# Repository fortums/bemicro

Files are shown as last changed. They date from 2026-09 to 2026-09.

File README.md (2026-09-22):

<h1>Bemicro</h1>
A macropad designed for Hackclub's Stardance.<br>
This is a half macropad half beatmania controller inspired by the <a href="https://github.com/ianklug/bemini">Bemini</a>.<br>
This was started on the 12th, and is now concluding on the 21st. not too bad for a first hardware project, if i do say so myself.<br>

AI FREE!!
<br><br>
<h2>the board itself</h2>
This was probably the most fun part. <br>
The keys (including the encoder button) are wired in a matrix with diodes. Theres 4 Neopixel LEDs in a row, A rotary encoder, and a small OLED screen.
<br> Every pin of the Xiao RP2040 is used except for the 3.3v pin, which is unneeded here.<br>

<br>
wiring it was also pretty fun, but not as much, it was a lot of doing and then redoing.<br>
i ended up with this masterfully (horribly) wired board<br>

<br>
which looks like this in the 3d view<br>

<br><br>
<h2>The case!</h2>
its really bare bones. The Xiao, leds, keyswitches, and roatary encoder all need to be left (mostly) uncovered, so theres not much to really add a top over, so theres no top. for now.(if i feel its needed once its built, i will make one.)
<br><br>
notably, the encoder knob (to mirror a beatmania controller) looks like a tunrtable... kinda. its that odd shape so that it can still be spin-able dj style, but also not cover the whole board.<br>
<br>
the board screws into the case (with the keyswitches facing "south" and the indent in the case facing "north"). the "turntable" friction fits over the D shaft of the rotary encoder.
<h2>qmk...</h2>
man qmk was a headache. it was quite the process to get rolling, mostly the guide was not at all for this usecase. but, with some perseverance and a bit of luck i figured it out.<br>
the default keybinds are as follows.<br>
  S,  D,  F,   ESC(on rotary encoder)<br>
Z,  X,  C,  V<br><br>
The rotary encoder itself types G on a counter clockwise turn and B on a clockwise turn <br>
holding the rotary encoder button also enables the led control layer, for as long as you hold it.<br>
the binds are <br>
       Hue up,    Sat up,    Val up,    ____(you should be holding this anyways)<br>
hue down,  sat down,   val down,    toggle underglow.<br>
there isnt yet a "macro"pad layer, but there will be in the future.<br><br>
<h1>bill of materials</h1>
1x Seeed Studio Xiao RP2040<br>
8x Through-hole 1N4148 diodes<br>
7x MX-style keyswitches<br>
1x EC11E rotary encoder (the kind with a switch)<br>
1x .91 inch OLED display<br>
7x MX keycaps (white in this case)<br>
2x M3x16mm screws<br>
2x M3x5x4mm heatset inserts.<br>
4x SK6812 MINI-E LEDs

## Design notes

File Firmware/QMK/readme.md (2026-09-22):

# bemicro

bemicro

*A short description of the keyboard/project*

* Keyboard Maintainer: [cnythia nosurname](https://github.com/fortums)
* Hardware Supported: *The PCBs, controllers supported*
* Hardware Availability: *Links to where you can find this hardware*

Make example for this keyboard (after setting up your build environment):

    make bemicro:default

Flashing example for this keyboard:

    make bemicro:default:flash

See the [build environment setup](https://docs.qmk.fm/#/getting_started_build_tools) and the [make instructions](https://docs.qmk.fm/#/getting_started_make_guide) for more information. Brand new to QMK? Start with our [Complete Newbs Guide](https://docs.qmk.fm/#/newbs).

## Bootloader

Enter the bootloader in 3 ways:

* **Bootmagic reset**: Hold down the key at (0,0) in the matrix (usually the top left key or Escape) and plug in the keyboard
* **Physical reset button**: Briefly press the button on the back of the PCB - some may have pads you must short instead
* **Keycode in layout**: Press the key mapped to `QK_BOOT` if it is available

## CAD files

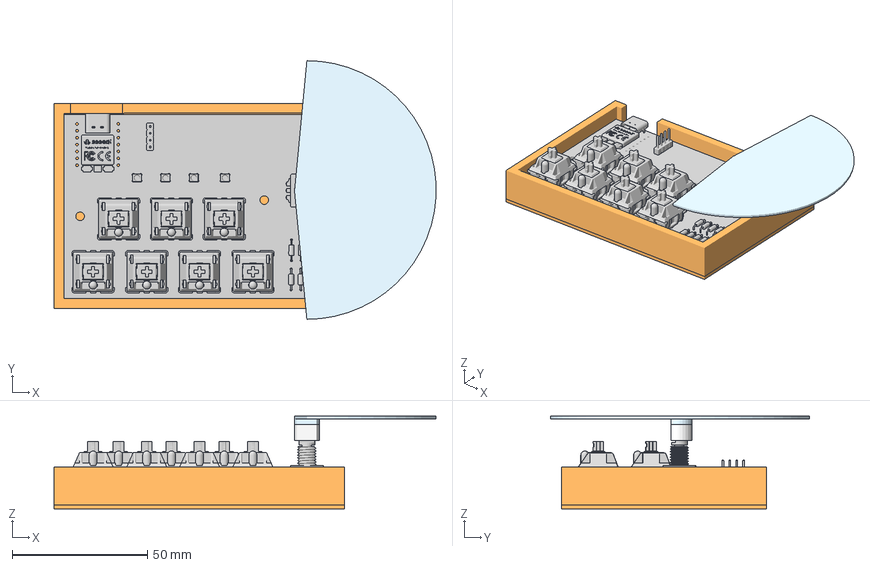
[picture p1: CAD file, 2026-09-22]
CAD/Full_Model.3mf
141.1 x 95.5 x 34.2 mm

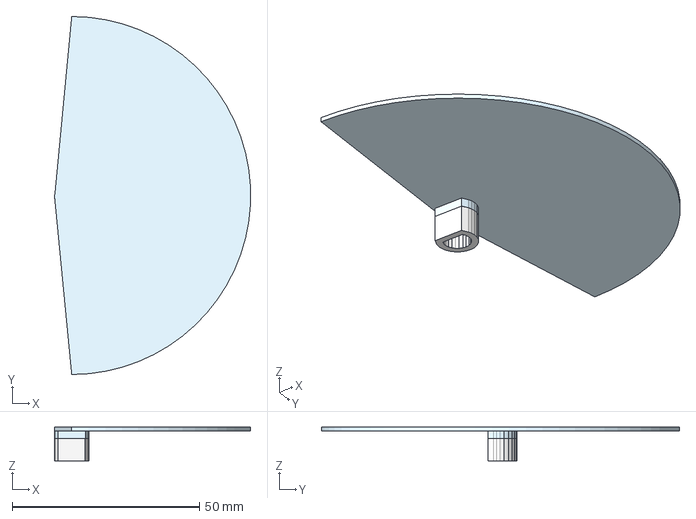
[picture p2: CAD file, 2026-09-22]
production/turntable.step
52.3 x 95.5 x 9.02 mm

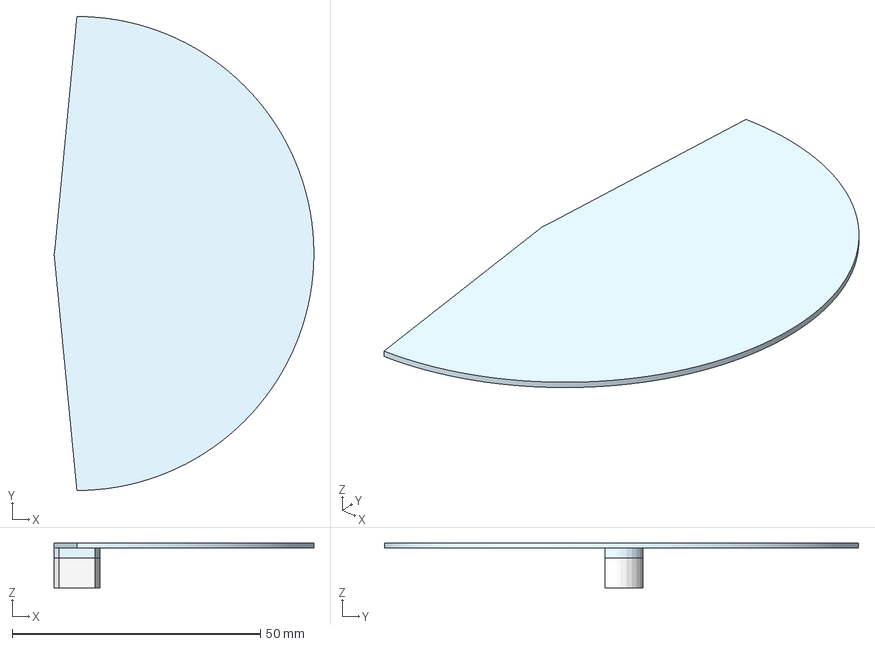
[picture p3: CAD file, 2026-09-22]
CAD/turntable.3mf
52.3 x 95.5 x 9.02 mm

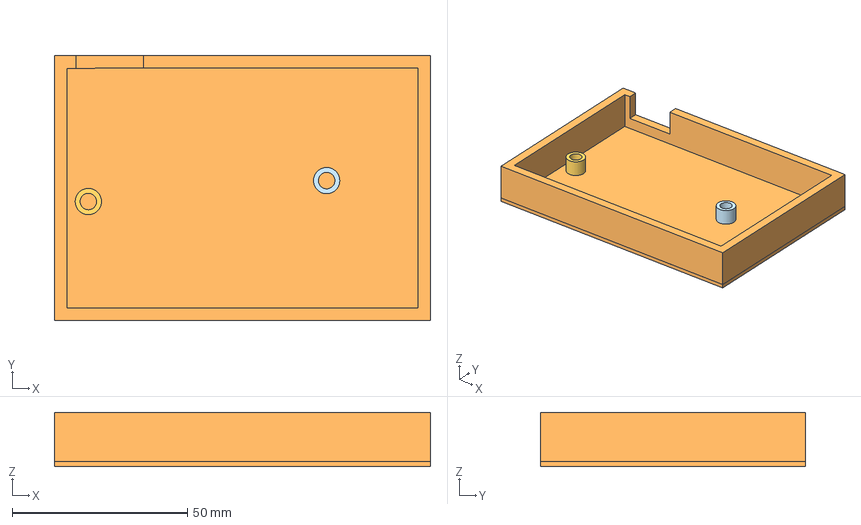
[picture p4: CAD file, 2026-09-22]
production/case_bottom.step
107.3 x 75.7 x 15.5 mm

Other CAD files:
CAD/Case_topless.3mf

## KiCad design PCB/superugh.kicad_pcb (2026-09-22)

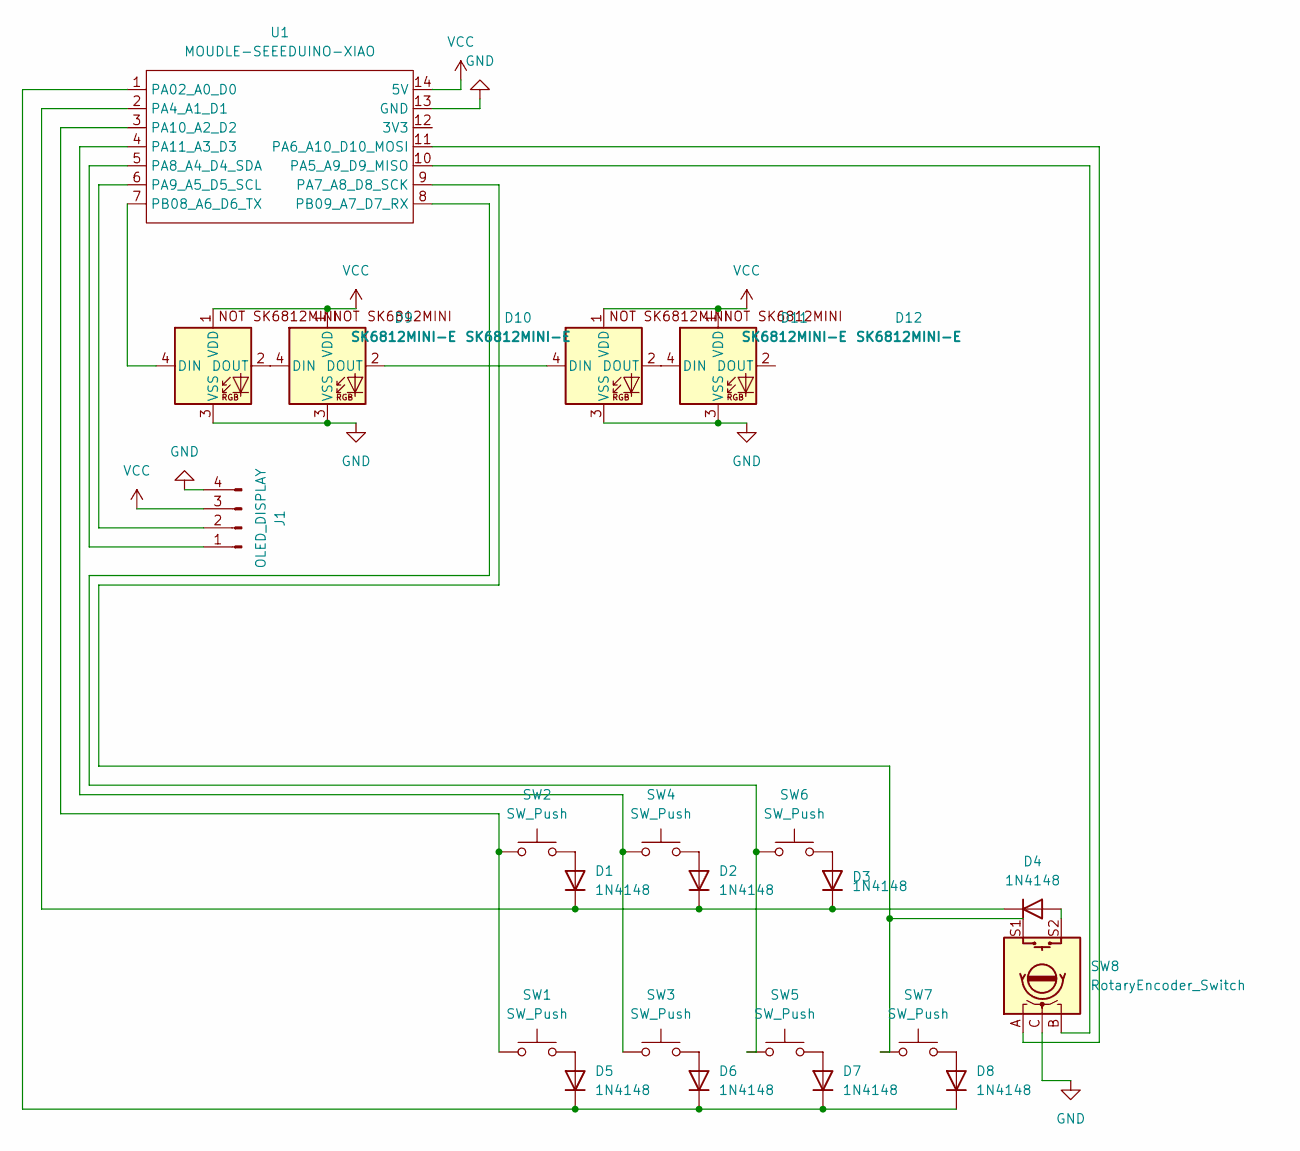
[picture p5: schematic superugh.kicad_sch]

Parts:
D1, D2, D3, D4, D5, D6, D7, D8: 1N4148; D_DO-35_SOD27_P7.62mm_Horizontal
D9, D10, D11, D12: SK6812MINI-E; LED_SK6812MINI-E_3.2x2.8mm_P1.5mm_ReverseMount
J1: OLED_DISPLAY; PinHeader_1x04_P2.54mm_Vertical
SW1, SW2, SW3, SW4, SW5, SW6, SW7: SW_Push; SW_Cherry_MX_1.00u_PCB
SW8: RotaryEncoder_Switch; RotaryEncoder_Alps_EC11E-Switch_Vertical_H20mm
U1: MOUDLE-SEEEDUINO-XIAO; XIAO-Generic-Hybrid-14P-2.54-21X17.8MM

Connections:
GND: D9.3 (VSS), D10.3 (VSS), D11.3 (VSS), D12.3 (VSS), J1.4, SW8.C, U1.13 (GND)
unnamed: D1.2 (A), SW2.2
unnamed: D1.1 (K), D2.1 (K), D3.1 (K), D4.1 (K), U1.2 (PA4_A1_D1)
unnamed: D2.2 (A), SW4.2
unnamed: D3.2 (A), SW6.2
unnamed: D4.2 (A), SW8.S2
unnamed: D5.2 (A), SW1.2
unnamed: D5.1 (K), D6.1 (K), D7.1 (K), D8.1 (K), U1.1 (PA02_A0_D0)
unnamed: D6.2 (A), SW3.2
unnamed: D7.2 (A), SW5.2
unnamed: D8.2 (A), SW7.2
unnamed: D9.4 (DIN), U1.7 (PB08_A6_D6_TX)
unnamed: D9.2 (DOUT), D10.4 (DIN)
unnamed: D10.2 (DOUT), D11.4 (DIN)
unnamed: D11.2 (DOUT), D12.4 (DIN)
unnamed: J1.1, U1.5 (PA8_A4_D4_SDA)
unnamed: J1.2, U1.6 (PA9_A5_D5_SCL)
unnamed: SW8.B, U1.10 (PA5_A9_D9_MISO)
unnamed: SW8.A, U1.11 (PA6_A10_D10_MOSI)
unnamed: SW7.1, SW8.S1, U1.9 (PA7_A8_D8_SCK)
unnamed: SW1.1, SW2.1, U1.3 (PA10_A2_D2)
unnamed: SW3.1, SW4.1, U1.4 (PA11_A3_D3)
unnamed: SW5.1, SW6.1, U1.8 (PB09_A7_D7_RX)
VCC: D9.1 (VDD), D10.1 (VDD), D11.1 (VDD), D12.1 (VDD), J1.3, U1.14 (5V)

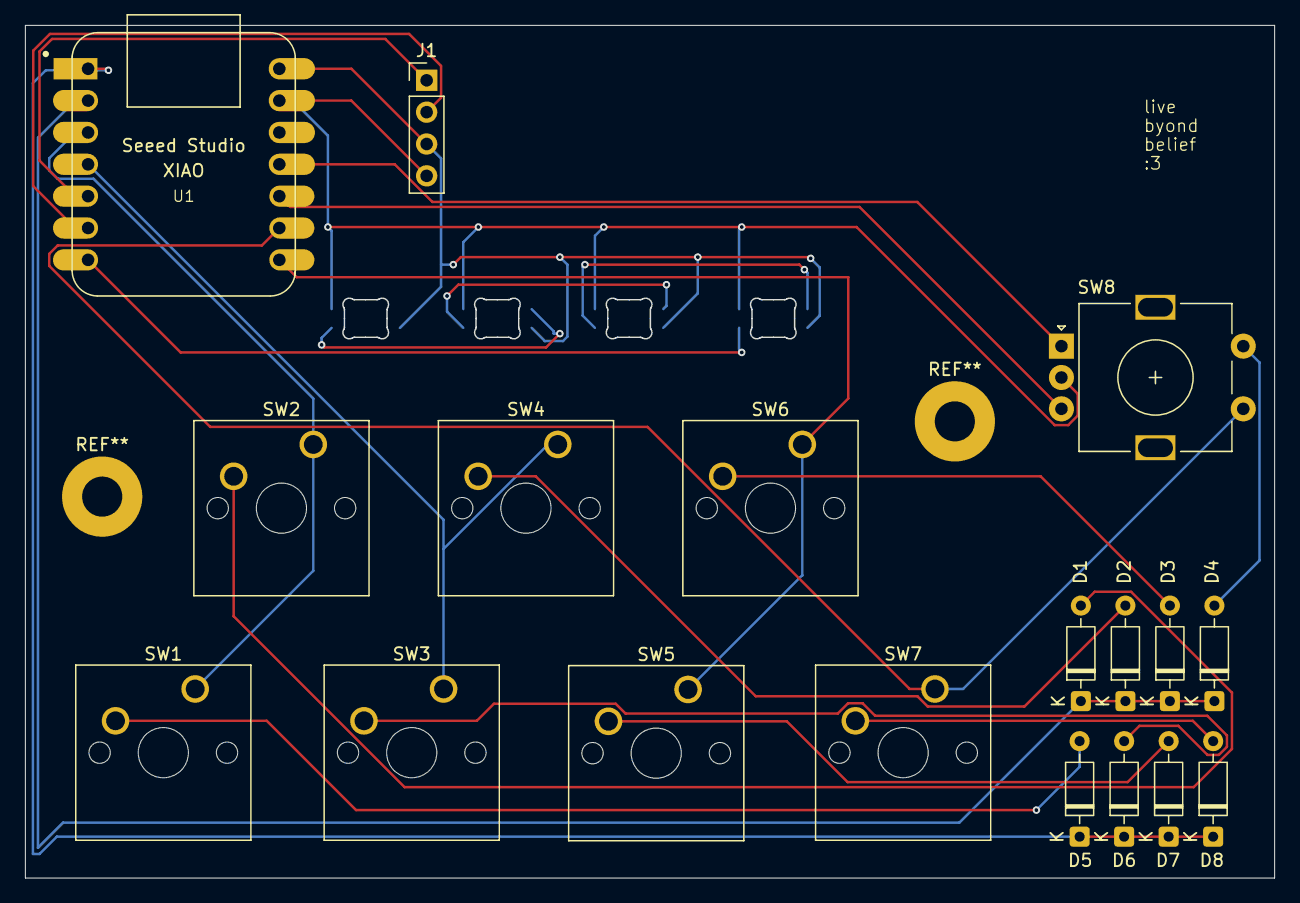
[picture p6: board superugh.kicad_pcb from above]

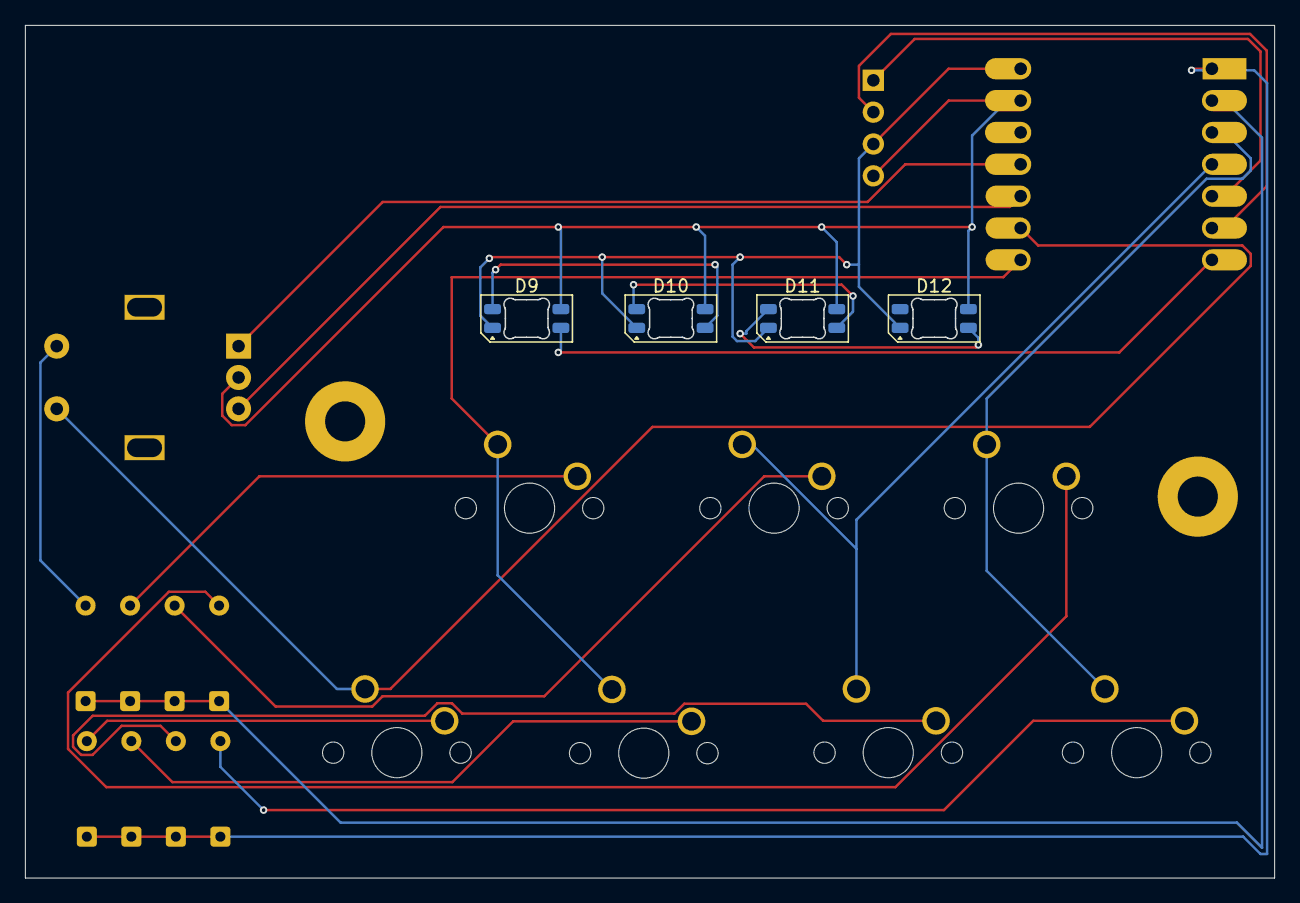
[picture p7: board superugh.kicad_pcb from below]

Board: 2 copper layers, 99.6 x 68.0 mm, 22 parts (4 on the bottom side), 24 nets.

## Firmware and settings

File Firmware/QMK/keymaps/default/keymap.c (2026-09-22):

// Copyright 2023 QMK
// SPDX-License-Identifier: GPL-2.0-or-later

#include QMK_KEYBOARD_H
enum layer_names {
    BEAT,
    FUNC
};
const uint16_t PROGMEM keymaps[][MATRIX_ROWS][MATRIX_COLS] = {
    /*
     *                   ┌───-┐ 
     *  ┌───┬───┬───┐    |ESC*| *is the rotary encoder button, hold for light control toggle.
     *  | S | D | F |    └───-┘
     *  └───┴───┴───┘ 
     *┌───┬───┬───┬───┐
     *| Z | X | C | V |
     *└───┴───┴───┴───┘
     */
    [BEAT] = LAYOUT(
       KC_S, KC_D, KC_F, LT(FUNC, KC_ESC),
        KC_Z, KC_X, KC_C, KC_V
    ),
        [FUNC] = LAYOUT(
       QK_UNDERGLOW_HUE_UP, QK_UNDERGLOW_SATURATION_UP, QK_UNDERGLOW_VALUE_UP, LT(FUNC, KC_ESC),
        QK_UNDERGLOW_HUE_DOWN, QK_UNDERGLOW_SATURATION_DOWN, QK_UNDERGLOW_VALUE_DOWN, QK_UNDERGLOW_TOGGLE
    ),
};

#ifdef OLED_ENABLE
bool oled_task_user(void) {
    // Host Keyboard Layer Status
    oled_write_P(PSTR("Layer: "), false);

    switch (get_highest_layer(layer_state)) {
        case BEAT:
            oled_write_P(PSTR("BEAT\n"), false);
            break;
        case FUNC:
            oled_write_P(PSTR("FUNC\n"), false);
            break;
        default:
            oled_write_ln_P(PSTR("Undefined"), false);
    }
    // Host Keyboard LED Status
    led_t led_state = host_keyboard_led_state();
    oled_write_P(led_state.num_lock ? PSTR("NUM ") : PSTR("    "), false);
    oled_write_P(led_state.caps_lock ? PSTR("CAP ") : PSTR("    "), false);
    oled_write_P(led_state.scroll_lock ? PSTR("SCR ") : PSTR("    "), false);
    
    return false;
};
#endif

#if defined(ENCODER_MAP_ENABLE)
const uint16_t PROGMEM encoder_map[][NUM_ENCODERS][1] = {
          // Mappings for 1st Encoder          // Mappings for 2nd Encoder
    [BEAT] = { ENCODER_CCW_CW(KC_G, KC_B)}, // Mapping for Base layer
    [FUNC] = { ENCODER_CCW_CW(KC_TRANSPARENT, KC_TRANSPARENT)} // Mapping for Layer 1
    // You can add more layers here if you need them, or you can also delete lines for layers you are not using
};
#endif
